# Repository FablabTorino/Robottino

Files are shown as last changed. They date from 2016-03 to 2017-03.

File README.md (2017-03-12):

#ROBOTTINO - testa rotante interattiva

[**WWW.ROBOTTINO.CC**](http://robottino.cc)

Robottino

## Licenza
[Creative Commons: Attribution-ShareAlike 4.0 International](http://creativecommons.org/licenses/by-sa/4.0/)

***
powered by [**Tongatron**](http://tongatron.it/)  
hosted and developed in [**Fablab Torino**](http://fablabtorino.org/)

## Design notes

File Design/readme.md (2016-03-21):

**Material for Robottino case**: MDF 3mm thickness

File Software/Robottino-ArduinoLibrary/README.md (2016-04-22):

#ROBOTTINO - testa rotante interattiva

[**WWW.ROBOTTINO.CC**](http://robottino.cc/test/)

Robottino

##Il robot
**Attuatori**

- TESTA ROTANTE (motore servo)
- SUONI (piezo)
- NASO (Led RGB)
- BOCCA (display)

**Sensori**

- SENSORI DI LUCE (LDR)
- SENSORE DI DISTANZA (Ultrasonic Distance Sensor)

##Installazione

 1. Installa l'ultima versione dell'**Arduino IDE**.		
 Scarica Arduino da qui: [www.arduino.cc/en/Main/Software](https://www.arduino.cc/en/Main/Software)
 2. Installa la **libreria u8glib** necessaria per la gestione del display.		
In Arduino: *Sketch > Include Library > Manage Libraries...*			
Cerca e installa la libreria denominata "u8glib"	
 3. Installa la **libreria Robottino**:			
 Scarica lo .zip da qui [Robottino-ArduinoLibrary.zip](http://robottino.cc/documents/Robottino-ArduinoLibrary.zip).			
 In Arduino: *Sketch > Include Library > Add .ZIP Library*

##Hello World
Il seguente programma esemplificativo mostra alcune funzioni base del Robottino:

```Arduino
#include "Robottino.h"
Robottino Peppino;
void setup() {
  	Peppino.begin();
	}
void loop() {
  Peppino.naso(verde);
  Peppino.espressione(felice);
  Peppino.beep(silenzio);     
  Peppino.ruota(lento); 
}
```

#Reference

[github.com/FablabTorino/Robottino/wiki/Reference](https://github.com/FablabTorino/Robottino/wiki/Reference)

##Pinout
Componente | PIN
------------ | -------------
Buzzer | 13
Led Red | 11
Led Green | 10
Led Blue | 9
Servo Motor | 8
Ultrasonic Trigger | 7
Ultrasonic Echo | 4
Right LDR | A0
Left LDR | A1

## Credits
Hanno contribuito al software:

- Carmine Paolino - [github.com/cancelliere](https://github.com/cancelliere)
- Giovanni Bindi - [github.com/tongatron](https://github.com/tongatron)
- Fedele Tagarelli - [https://github.com/tagaf](https://github.com/tagaf)

## Licenza
[Creative Commons: Attribution-ShareAlike 4.0 International](http://creativecommons.org/licenses/by-sa/4.0/)

***
powered by [**Tongatron**](http://tongatron.it/)  
hosted and developed in [**Fablab Torino**](http://fablabtorino.org/)

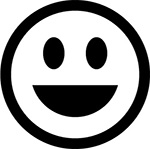
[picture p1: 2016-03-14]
Education/tangible interface/jpeg resize/display.jpg

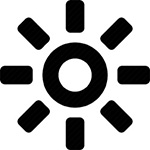
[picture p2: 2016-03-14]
Education/tangible interface/jpeg resize/luce.jpg

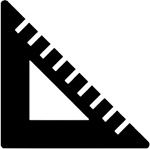
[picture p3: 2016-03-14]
Education/tangible interface/jpeg resize/distanza.jpg

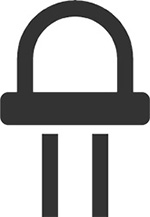
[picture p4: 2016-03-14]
Education/tangible interface/jpeg resize/led.jpg

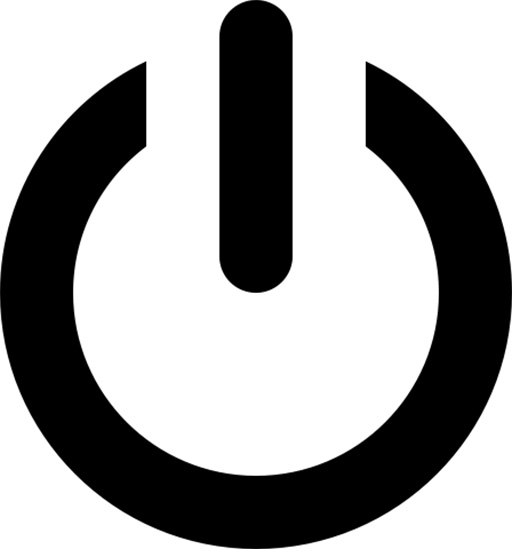
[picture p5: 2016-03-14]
Education/tangible interface/jpeg resize/power.jpg

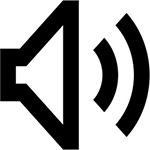
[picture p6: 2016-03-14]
Education/tangible interface/jpeg resize/suono.jpg

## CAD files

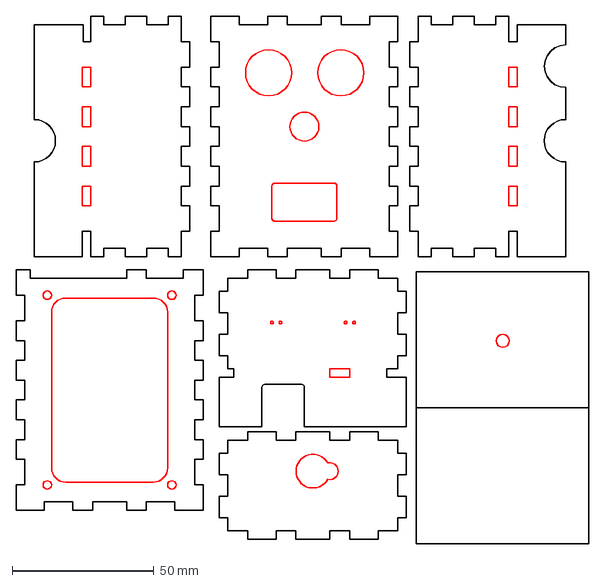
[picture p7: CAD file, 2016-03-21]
Design/robottino-case.dxf
202.2 x 186.3 mm

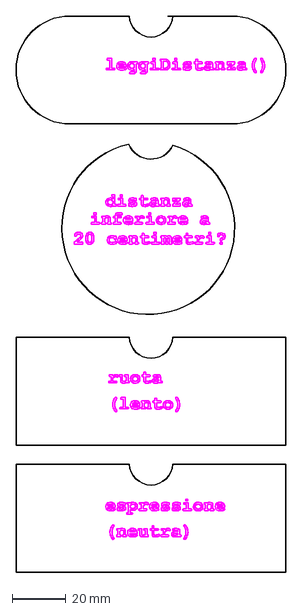
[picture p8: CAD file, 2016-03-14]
Education/tangible interface/blocchetti aggiuntivi.dxf
100.0 x 206.0 mm

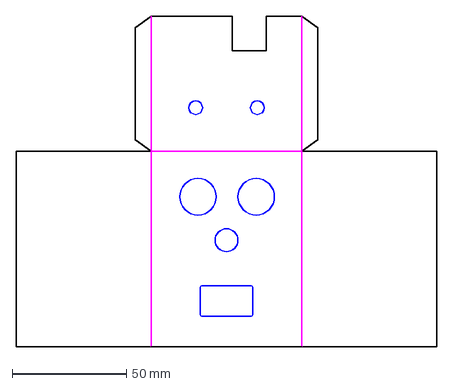
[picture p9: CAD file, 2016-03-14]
Design/robottino-cardboardmask.dxf
184.0 x 144.6 mm

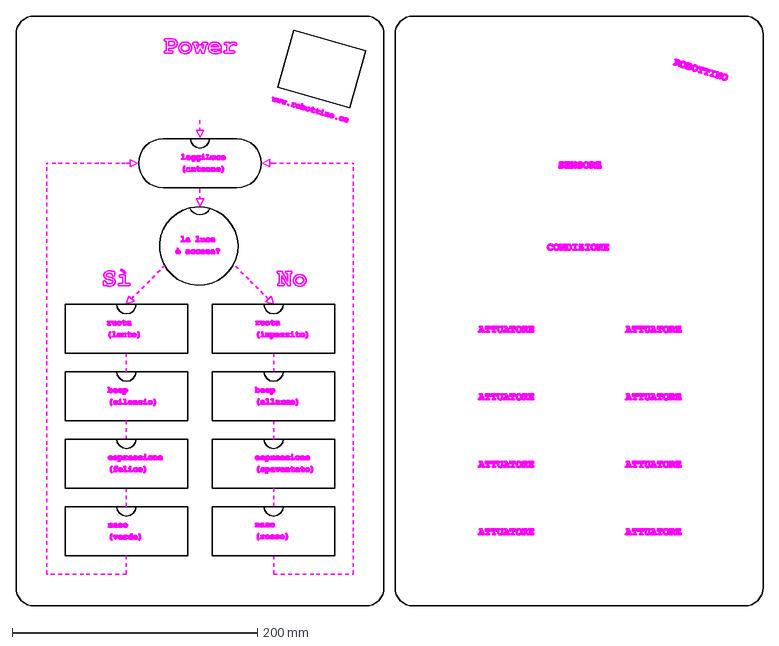
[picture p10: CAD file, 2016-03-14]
Education/tangible interface/block programming robottino.dxf
609.0 x 481.0 mm

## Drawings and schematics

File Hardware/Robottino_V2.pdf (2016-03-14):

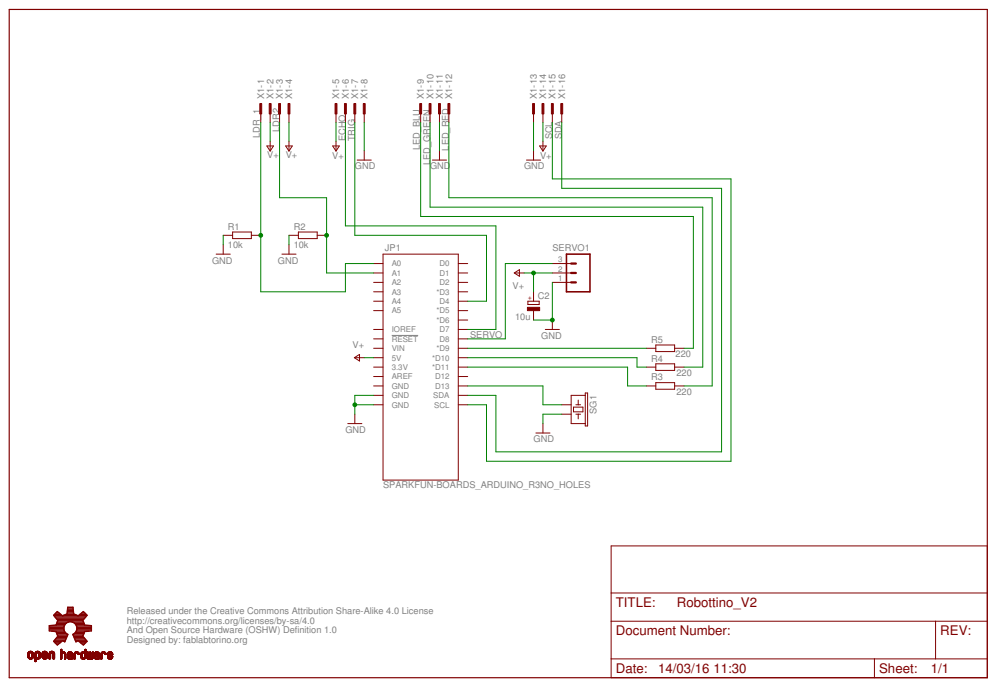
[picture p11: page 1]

Released under the Creative Commons Attribution Share-Alike 4.0 License
http://creativecommons.org/licenses/by-sa/4.0
And Open Source Hardware (OSHW) Definition 1.0
Designed by: fablabtorino.org

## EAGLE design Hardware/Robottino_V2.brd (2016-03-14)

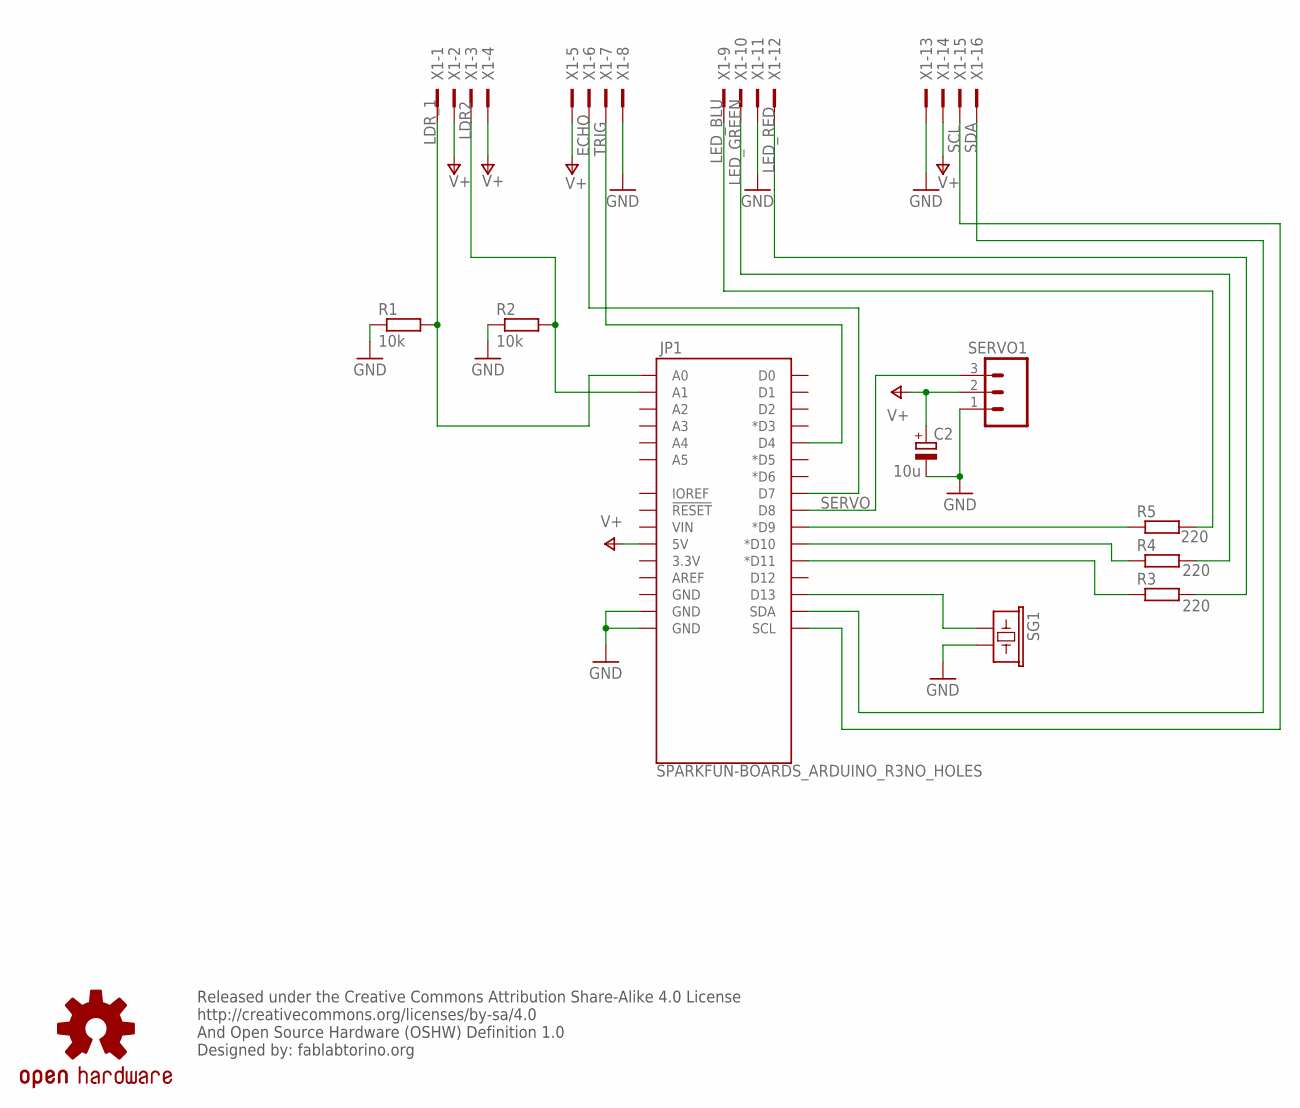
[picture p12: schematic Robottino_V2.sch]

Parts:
C2: 10u; E2,5-6
JP1: SPARKFUN-BOARDS_ARDUINO_R3NO_HOLES; SPARKFUN-BOARDS_ARDUINO_R3_NO_HOLES
LOGO1: OSHW-LOGOS; OSHW-LOGO-S
R1, R2: 10k; 0309/10
R3, R4, R5: 220; 0309/10
SERVO1: M03POLAR; MOLEX-1X3
SG1: SPARKFUN-ELECTROMECHANICAL_BUZZERPTH-NS-KIT; SPARKFUN-ELECTROMECHANICAL_BUZZER-12MM-NS-KIT
X1: 2516-; PAK100/2500-16

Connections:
BUZZER: JP1.D13, SG1.+ (1)
ECHO: JP1.D4, X1.7
GND: C2.-, JP1.GND@1 (GND), JP1.GND@2 (GND), R1.1, R2.1, SERVO1.1, SG1.- (2), X1.8, X1.11, X1.13
LDR2: JP1.A1, R2.2, X1.3
LDR_1: JP1.A0, R1.2, X1.1
LED_BLU: R5.2, X1.9
LED_GREEN: R4.2, X1.10
LED_RED: R3.2, X1.12
unnamed: JP1.D9 (*D9), R5.1
unnamed: JP1.D10 (*D10), R4.1
R: JP1.D11 (*D11), R3.1
SCL: JP1.SCL, X1.15
SDA: JP1.SDA, X1.16
SERVO: JP1.D8, SERVO1.3
TRIG: JP1.D7, X1.6
V+: C2.+, JP1.5V, SERVO1.2, X1.2, X1.4, X1.5, X1.14

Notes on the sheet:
Released under the Creative Commons Attribution Share-Alike 4.0 License http://creativecommons.org/licenses/by-sa/4.0 And Open Source Hardware (OSHW) Definition 1.0 Designed by: fablabtorino.org

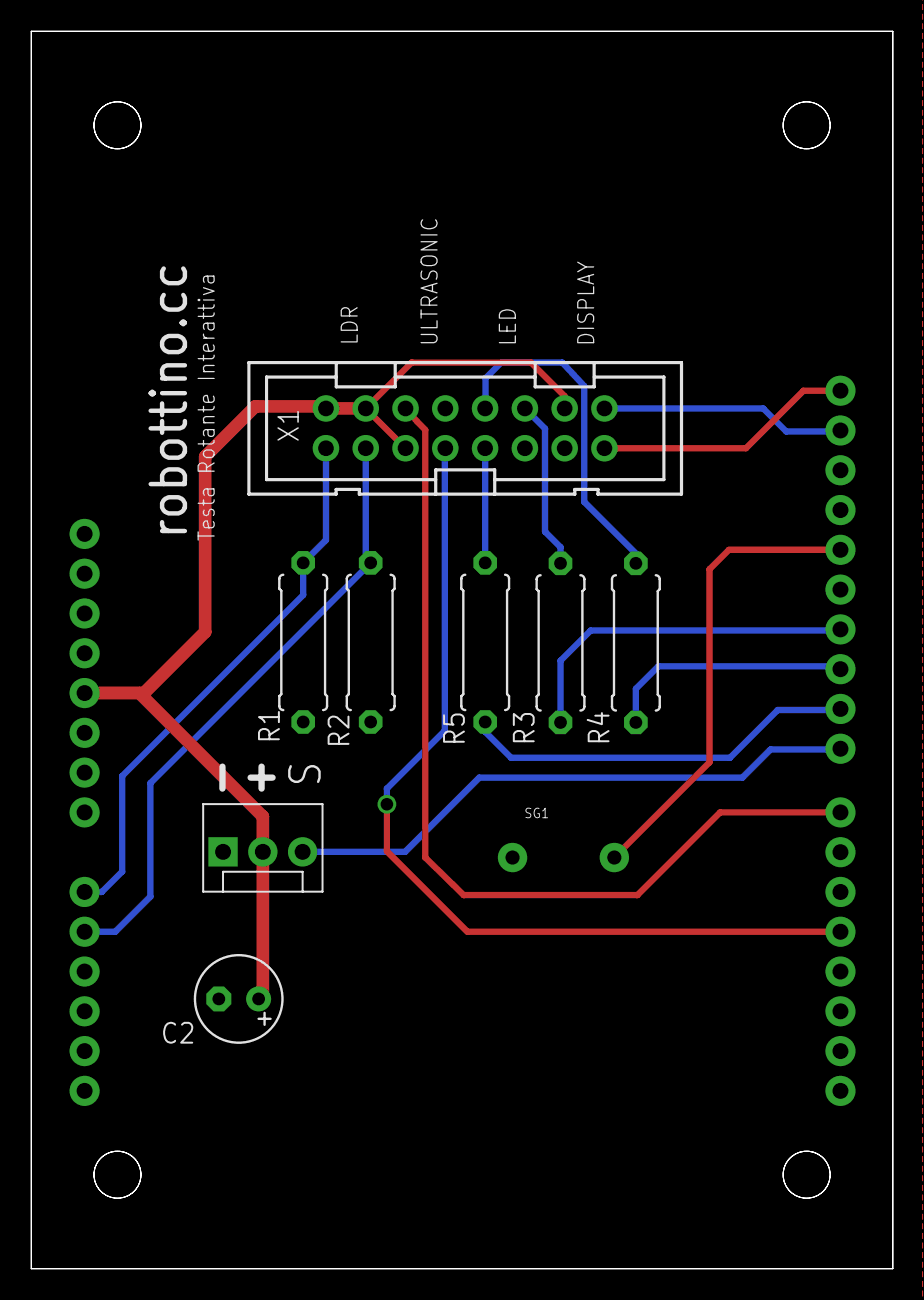
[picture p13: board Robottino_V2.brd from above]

Board: 2 copper layers, 55.0 x 79.0 mm, 11 parts (0 on the bottom side), 16 nets.

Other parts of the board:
E$1: OSHW-LOGO-S_COPPER

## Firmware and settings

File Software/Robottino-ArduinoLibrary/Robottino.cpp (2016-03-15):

#include "Robottino.h"

#define BUZZ_PIN 13
#define RED_PIN 11
#define GRN_PIN 10
#define BLU_PIN 9
#define SERVO_PIN 8
#define TRIG_PIN 7
#define ECHO_PIN 4
#define LDR_DX_PIN A0
#define LDR_SX_PIN A1

#define ANGLE_STEP 1
#define ANGLE_BOUND 40

#define THRESHOLD1 600  // used when controlling the speed with light intensity
#define THRESHOLD2 300


//RGB fade timing
#define STEP_DURATION 100        // since one display refresh takes around 110 ms while reading the sensors' values, this delay is larger to avoid any influence
#define HOLD_DURATION 0        // Optional hold when a color is complete, before the next crossFade
#define STEP_WIDTH 10
#define TOTAL_STEPS 240

#define DISPLAY_DELAY 100

SoftwareServo servo;


// ----------RGB (Nose) behaviour definition----------

// Color arrays
int nero[3]  = { 0, 0, 0 };		//black
int bianco[3]  = { 240, 240, 240 };	//white
int rosso[3]    = { 240, 0, 0 };	//red
int arancio[3] = { 240, 120, 0};	//orange
int giallo[3] = { 120, 240, 0 };	//yellow
int verde[3]  = { 0, 240, 0 };		//green
int blu[3]   = { 0, 0, 240 };		// blu
int indaco[3] = { 120, 0, 120 };	//indigo
int viola[3] = { 240, 120, 240 };	//purple
int arcobaleno[3] = { -1, 0, 0};	//rainbow (Needs a workaround because of compatibility problems between PWN on pin 11 and the tone() function)

// Set initial color
int redVal = nero[0];
int grnVal = nero[1];
int bluVal = nero[2];

// Initialize color variables
int prevR = redVal;
int prevG = grnVal;
int prevB = bluVal;

unsigned long currentRGBMillis;       // used to control the fading speed of the rainbow
unsigned long previousRGBMillis = 0;

unsigned long currentBlinkMillis;     // used in "nasoLampeggiante"
unsigned long previousBlinkMillis = 0;

byte evalFadeHold = 0;            // 0: evaluate parameters - 1: fade - 2: hold
int RGBStep = 0;                  // index used during the progress of "crossFade"
int R, G, B;                      // RGB values to reach at the end of a "crossFade"
int stepR, stepG, stepB;          // from the beginning to the end of a "crossFade" each colour is changed every step"X"
byte currentColour = 3;           // index used during the progress of "naso(arcobaleno)", see the function to see why it starts from 3
bool blinkStep = 0;

void RGBInit() {
  pinMode(RED_PIN, OUTPUT);
  pinMode(GRN_PIN, OUTPUT);
  pinMode(BLU_PIN, OUTPUT);
}

// Evaluate the width of a step based on the actual value end the one to reach, for a single light component (R, G or B)
// The value returned can be negative, so byte data type cannot be used
int calculateStep (int prevValue, int endValue) {
  int step = (endValue - prevValue)/STEP_WIDTH;
  if (step) {                     // If its non-zero
    step = TOTAL_STEPS/step;              // In the worst case (0->255) the brightness is adjusted each step
  }
  return step;
}

// Evaluate the actual light component value
int calculateVal(int step, int val, int counter) {
  if ((step) && counter % step == 0) {    // If step is non-zero and its time to change a value,
    if (step > 0 && val <= 255 - STEP_WIDTH) {    //   increment the value if step is positive and not next to maximum...
      val += STEP_WIDTH;
    }
    else if (step < 0 && val >= 0 + STEP_WIDTH) { //   ...or decrement it if step is negative and not next to 0
      val -= STEP_WIDTH;
    }
  }
  return val;
}


void crossFade(int color[3]) {
  currentRGBMillis = millis();

  if (evalFadeHold == 0) {
    //R = color[0];
    G = color[1];
    B = color[2];
    //stepR = calculateStep(prevR, R);
    stepG = calculateStep(prevG, G);
    stepB = calculateStep(prevB, B);

    evalFadeHold = 1;
  }

  else if (currentRGBMillis - previousRGBMillis >= STEP_DURATION && evalFadeHold==1) {  // Fade

    //redVal = calculateVal(stepR, redVal, RGBStep);
    grnVal = calculateVal(stepG, grnVal, RGBStep);
    bluVal = calculateVal(stepB, bluVal, RGBStep);

    //analogWrite(RED_PIN, redVal);     // the tone() function conflicts with PWM on pin 11 (RED), so to avoid weird noises we do not use RED fading
    analogWrite(GRN_PIN, grnVal);
    analogWrite(BLU_PIN, bluVal);

    previousRGBMillis = currentRGBMillis;
    RGBStep+=STEP_WIDTH;

    if( RGBStep >= TOTAL_STEPS ) {
      evalFadeHold = 2;
      RGBStep = 0;
    }
  }

  // Update current values for next loop
  else if (currentRGBMillis - previousRGBMillis >= HOLD_DURATION && evalFadeHold==2) {  // Hold
    prevR = redVal;
    prevG = grnVal;
    prevB = bluVal;
    previousRGBMillis = currentRGBMillis;
    evalFadeHold = 0;

    currentColour ++;
  }
}

// Rainbow


void Robottino::naso (int col[3]) {	//naso = nose
  if (col[0] == -1) {  // Rainbow
    switch (currentColour) {  // since we can't use the red LED, we won't show colours mainly composed of that kind of light
      /*
      case 0:
        crossFade(rosso);
        break;
      case 1:
        crossFade(arancio);
        break;
      case 2:
        crossFade(giallo);
        break;
        */
      case 3:
        crossFade(verde);
        break;
      case 4:
        crossFade(blu);
        break;
      case 5:
        crossFade(viola);
        break;
      default:
        currentColour = 3;
    }
  }
  else {    // Fixed colours
    analogWrite(RED_PIN, col[0]);
    analogWrite(GRN_PIN, col[1]);
    analogWrite(BLU_PIN, col[2]);
  }
}

void Robottino::nasoLampeggiante (int col[3], int interval) {  //nasoLampeggiante = blinkingNose
  currentBlinkMillis = millis();
  if (currentBlinkMillis - previousBlinkMillis >= interval) {
    if (!blinkStep) {       // Alternate between the wanted colour...
      naso(col);
      blinkStep ^= 1;
    }
    else {
      naso(nero); // ... and a turned off LED
      blinkStep ^= 1;
    }
    previousBlinkMillis = currentBlinkMillis;
  }
}


// ----------Sensors behaviour definition----------

void sensorsInit() {
  pinMode(LDR_DX_PIN, INPUT);
  pinMode(LDR_SX_PIN, INPUT);
  pinMode(TRIG_PIN, OUTPUT);
  pinMode(ECHO_PIN, INPUT);
}


// ----------Eyes----------
int distanzaRilevata;
unsigned long previousSonicMillis = 0;

// Returns distance in cm
int Robottino::leggiDistanza () {               //can't use newPing library because of compatibility problems with tone() on Arduino UNO
  if (millis() - previousSonicMillis > 50) {
    digitalWrite(TRIG_PIN, HIGH);   //(see: http://forum.arduino.cc/index.php?topic=184162.0 )
    delay(1);
    digitalWrite(TRIG_PIN, LOW);
    int distance = pulseIn(ECHO_PIN, HIGH, 5700) / 57;  //Timeout if distance > 100 cm; divide by round-trip microseconds per cm to get cm
    distanzaRilevata = distance;
    previousSonicMillis = millis();
  }
  return distanzaRilevata;
}

byte distanceThreshold = 20;

bool oggettoVicino () {
  Serial.println(distanzaRilevata);
  if (distanzaRilevata < distanceThreshold && distanzaRilevata != 0) return 1;
  else return 0;
}

int luceRilevata;
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

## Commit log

2016-03-14 prima pubblicazione
    [Robottino_V2.brd, Robottino_V2.sch, blocchetti aggiuntivi.dxf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]
2016-03-21 Case updated with right version of the robottino-case.dxf file
    [robottino-case.dxf]

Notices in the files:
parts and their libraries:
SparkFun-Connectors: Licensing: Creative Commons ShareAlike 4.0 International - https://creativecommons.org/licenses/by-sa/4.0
